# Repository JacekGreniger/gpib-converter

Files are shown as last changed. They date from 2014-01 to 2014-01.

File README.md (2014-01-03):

gpib-converter
==============

GPIB to USB converter

Source code for the device published in Elektronika Praktyczna 2/2013

Short PB5 to GND during powering on to enter printer (dummy) mode. In this mode all data sent over GPIB
are transferred to PC (use your favourite terminal program to save data into file). Use this mode to get plots from your GPIB device (spectrum analyzer, oscilloscope).
Received plots can be rendered using KE5FX HP7470 emulator package. Printer mode can be also entered using
command "p".

ATmega32 is clocked using 12MHz clock taken from pin C0 of FT232RL USB to serial converter. Use programming
order as below:

1. Program FT232RL using proper utility (see hw/ft232_settings.jpg)
2. Program ATmega32 using ISP programmer (sw/gpib_conv_v4.hex)
3. Set proper fusebits (see hw/fusebits.jpg)

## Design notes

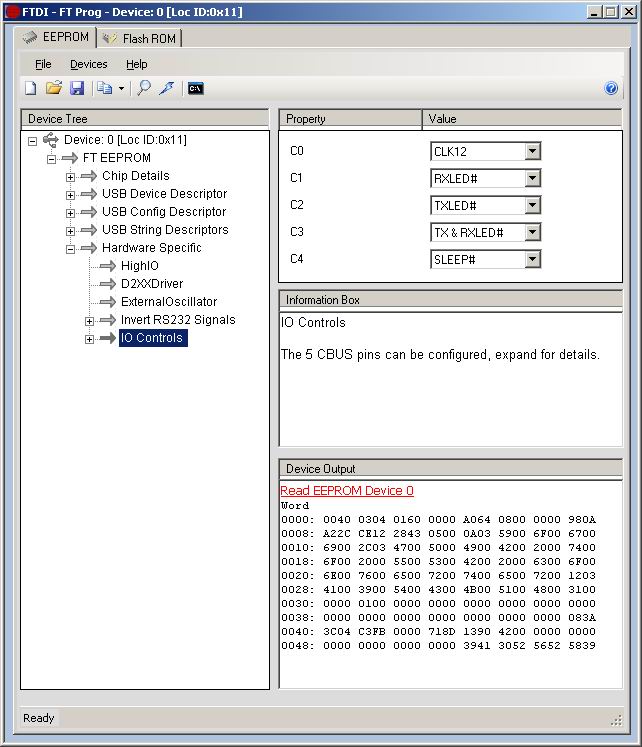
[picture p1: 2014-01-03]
hw/ft232_settings.jpg

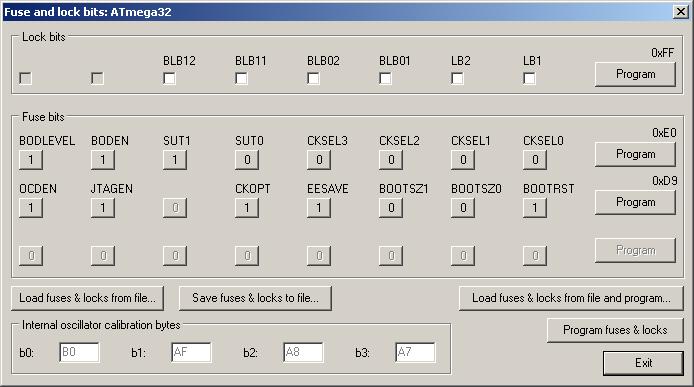
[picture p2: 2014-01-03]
hw/fusebits.jpg

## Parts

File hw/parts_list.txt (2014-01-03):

IC1 - ATmega32, TQFP44
IC2 - FT232RL
LED1 - LED 0805
R1 - 560ohm, 0805
C1 - 100nF, 0805
C2 - 4.7uF, 10V, B size
X1 - connector mini-usb (TME: ESB34101000Z, Farnell: 2112374)
Connector Wtyk 24pin Centronics (TME: CENTR-224, Farnell: 2112386)

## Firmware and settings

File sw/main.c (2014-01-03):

/* GPIB to USB converter
   ATMega32 + FT232RL
   clocked with external 12MHz taken from FT232RL (output 1)
   version 4, 20.08.2012
   
   Added feature:
    - possible to exit from printer mode
    - added help under command "?"
    - backspace support
    - commands scroll
    - printer mode, red led 
    - listen mode
    - M command for sending data without EOI
*/


#include <inttypes.h>
#include <stdio.h>
#include <stdlib.h>
#include <string.h>
#include <avr/io.h>
#include <stdbool.h>
#include <ctype.h>
#include "usart.h"
#include "avr/pgmspace.h"
#include <avr/interrupt.h>

#define F_CPU 12000000UL  
#include <util/delay.h>

#define DEFAULT_ADDRESS 21

/*
GPIB Connector pinout

Pin | Nazwa | Opis               | Source            | Atmega pin |	
----+-------+--------------------+-------------------+------------+--------
1   | DIO1  | Data bit 1 (LSB)   | Talker            | PA0	37    | X3-4
2   | DIO2  | Data bit 2         | Talker            | PA1	36    | X3-3
3   | DIO3  | Data bit 3         | Talker            | PA2	35    | X3-2
4   | DIO4  | Data bit 4         | Talker            | PA3	34    | X3-1
5   | EOI   | End Or Indentity   | Talker/Controller | PC7	26    | X4-1
6   | DAV   | Data Valid         | Controller        | PC6	25    | X4-2
7   | NRFD  | Not Ready For Data | Listener          | PC5	24    | X4-3
8   | NDAC  | No Data Accepted   | Listener          | PC4	23    | X4-4
9   | IFC   | Interface Clear    | Controller        | PC3	22    | X5-1
10  | SRQ   | Service Request    | Talker            | PC2	21    | X5-2
11  | ATN   | Attention          | Controller        | PC1	20    | X5-3
12  |       | Ekran              |                   |            |
13  | DIO5  | Data bit 5         | Talker            | PA4	33    | X2-4
14  | DIO6  | Data bit 6         | Talker            | PA5	32    | X2-3
15  | DIO7  | Data Bit 7         | Talker            | PA6	31    | X2-2
16  | DIO8  | Data bit 8 (MSB)   | Talker            | PA7	30    | X2-1
17  | REN   | Remote Enabled     | Controller        | PC0	19    | X5-4
18  |       | GND DAV            |                   |            |
19  |       | GND NRFD           |                   |            |
20  |       | GND NDAC           |                   |            |
21  |       | GND IFC	         |                   |            |
22  |       | GND SRQ	         |                   |            |
23  |       | GND ATN	         |                   |	          |
24  |       | GND data           |                   |	          | X3-5
*/

#define EOI (_BV(PC7))  //pin 26 ATmega, pin 5 GPIB
#define DAV (_BV(PC6))  //pin 25 ATmega, pin 6 GPIB
#define NRFD (_BV(PC5)) //pin 24 ATmega, pin 7 GPIB, output
#define NDAC (_BV(PC4)) //pin 23 ATmega, pin 8 GPIB, output
#define IFC (_BV(PC3))  //pin 22 ATmega, pin 9 GPIB
#define SRQ (_BV(PC2))  //pin 21 ATmega, pin 10 GPIB
#define ATN (_BV(PC1))  //pin 20 ATmega, pin 11 GPIB
#define REN (_BV(PC0))  //pin 19 ATmega, pin 17 GPIB

#define SetLed(x) ( PORTD = ((x==0)?(PORTD | _BV(PD2)) : (PORTD & ~_BV(PD2)) ))

#define SetEOI(x) ( PORTC = (x)? (PORTC | EOI) : (PORTC & ~EOI) )
#define SetDAV(x) ( PORTC = (x)? (PORTC | DAV) : (PORTC & ~DAV) )
#define SetNRFD(x) ( PORTC = (x)? (PORTC | NRFD) : (PORTC & ~NRFD) )
#define SetNDAC(x) ( PORTC = (x)? (PORTC | NDAC) : (PORTC & ~NDAC) )
#define SetIFC(x) ( PORTC = (x)? (PORTC | IFC) : (PORTC & ~IFC) )
#define SetSRQ(x) ( PORTC = (x)? (PORTC | SRQ) : (PORTC & ~SRQ) )
#define SetATN(x) ( PORTC = (x)? (PORTC | ATN) : (PORTC & ~ATN) )
#define SetREN(x) ( PORTC = (x)? (PORTC | REN) : (PORTC & ~REN) )

#define ESC_KEY_UP 0x41
#define ESC_KEY_DOWN 0x42
#define ESC_KEY_RIGHT 0x43
#define ESC_KEY_LEFT 0x44

#define MAX_COMMANDS 15
#define BUF_SIZE 64
#define GPIB_BUF_SIZE 128
#define GPIB_MAX_RECEIVE_TIMEOUT 50000
#define GPIB_MAX_TRANSMIT_TIMEOUT 50000
#define EMPTY_LINE 1

#define HELP_LINES 18
#define HELP_STRING_LEN 64
const char helpStrings[HELP_LINES][HELP_STRING_LEN] PROGMEM = {
  "GPIB to USB converter v4\r\n\r\n",
  "Transmit commands, OK/TIMEOUT/ERROR\r\n",
  "  <D> Data (ATN false), <M> Data without EOI\r\n",
  "  <C> Command (ATN true)\r\n",
  "  <T> Hex transmit (0C - command, 0D - data)\r\n",
  "Receive commands (receives until EOI,max 127 bytes)\r\n",
  "  <X> ASCII, <payload> or TIMEOUT\r\n",
  "  <Y> BINARY, <length><payload>\r\n",
  "  <Z> HEX, <length><payload>\r\n",
  "  <P> Continous read (plotter mode)\r\n",
  "General commands\r\n",
  "  <A> Set/get converter talk address\r\n",
  "  <S> Get REQ/SRQ/LISTEN state (1 if true)\r\n",
  "  <R> Set REMOTE mode (REN true)\r\n",
  "  <L> Set LOCAL mode (REN false)\r\n",
  "  <I> Generate IFC pulse\r\n",
  "  <E> Get/set echo on(E1)/off(E0)\r\n",
  "  <H> Commands history\r\n"
};


typedef enum {OFF = 0, SLOW, FAST} ledBlinking_t;
ledBlinking_t ledBlinking = OFF;
unsigned char listenAddress = DEFAULT_ADDRESS;
unsigned char msgEndSeq = 0;
unsigned char remoteState = 0;

/* ======================================================= */

void GPIO_init() {
  // DDR = 1 output
  // DDR = 0 input
  DDRD = 0x04; // PD2 output
  PORTD = 0x04; // leds off,

  DDRB = _BV(PB6); // PB6 output
  PORTB = _BV(PB5) | _BV(PB7); // PB5,PB7 pull-up
}


int uart_putchar(char ch, FILE* file)
{
  UART_transmit(ch);
  return ch;
}


void ReconfigureGPIO_GPIBReceiveMode()
{
  DDRA = 0x00; // PA0-PA7 inputs
  PORTA = 0xff; // pullup on
  
  DDRC = IFC | ATN | REN | NRFD | NDAC; // these lines are outputs, other as inputs
  PORTC = IFC | ATN | (remoteState?0:REN) | EOI | DAV | SRQ; // pullup on
}


void ReconfigureGPIO_GPIBNormalMode()
{
  DDRA = 0xff; // data lines are outputs
  PORTA = 0x00; // output level 0
  
  DDRC = IFC | ATN | REN | EOI | DAV; // these lines are outputs
  PORTC = IFC | ATN | (remoteState?0:REN) | EOI | DAV | SRQ | NRFD | NDAC; // pullup on
}


int GPIB_Receive(unsigned char * buf, unsigned char bufLength, unsigned char * receivedLength)
{
  unsigned char index = 0;
  unsigned char c;
  unsigned int timeout;

  do
  {
    SetNRFD(1); //ready for receiving data
    //-1 & 5
    
    timeout = 0;
    while (PINC & DAV) // waiting for falling edge
    {
      //_delay_ms(1);
      timeout++;
      if (timeout > GPIB_MAX_RECEIVE_TIMEOUT)
      {
        *receivedLength = index;
        SetNRFD(0);
        return 0;
      }
    }
    // 0
    
    SetNRFD(0); //not ready for receiving data
    // 1
    
    c = ~PINA; //read data

    buf[index++] = c;

    SetNDAC(1); //data accepted
    //2
    
    while (!(PINC & DAV)) // waiting for rising edge
    {
      //_delay_ms(1);
      timeout++;
      if (timeout > GPIB_MAX_RECEIVE_TIMEOUT)
      {
        *receivedLength = index;
        SetNDAC(0);
        return 0;
      }
    }
    //3
    
    SetNDAC(0);
    //4
  } while ((index < bufLength) /*&& (c != 13)*/);
  *receivedLength = index;
  return 255;
}


int GPIB_Receive_till_eoi(unsigned char * buf, unsigned char bufLength, unsigned char * receivedLength)
{
  unsigned char index = 0;
  unsigned char c;
  unsigned char eoi = 0;
  unsigned int timeout;

  do
  {
    SetNRFD(1); //ready for receiving data
    //-1 & 5
    
    timeout = 0;
    while (PINC & DAV) // waiting for falling edge
    {
      timeout++;
      if (timeout > GPIB_MAX_RECEIVE_TIMEOUT)
      {
        *receivedLength = index;
        SetNRFD(0);
        return 0;
      }
    }
    // 0
    
    if ((PINC & EOI) == 0)
      eoi = 1;
    
    SetNRFD(0); //not ready for receiving data
    // 1
    
    c = ~PINA; //read data

    buf[index++] = c;

    SetNDAC(1); //data accepted
    //2
    
    while (!(PINC & DAV)) // waiting for rising edge
    {
      timeout++;
      if (timeout > GPIB_MAX_RECEIVE_TIMEOUT)
      {
        *receivedLength = index;
        SetNDAC(0);
        return 0;
      }
    }
    //3
    
    SetNDAC(0);
    //4
  } while ((index < bufLength) && (eoi == 0));
  *receivedLength = index;
  return 255;
}


int GPIB_Receive_till_lf(unsigned char * buf, unsigned char bufLength, unsigned char * receivedLength)
{
  unsigned char index = 0;
  unsigned char c;
  unsigned int timeout;

  //SetNDAC(0);
  //SetNRFD(0);

  do
  {
    SetNRFD(1); //ready for receiving data
    //-1 & 5
    
    timeout = 0;
    while (PINC & DAV) // waiting for falling edge
    {
      timeout++;
      if (timeout > GPIB_MAX_RECEIVE_TIMEOUT)
      {
        *receivedLength = index;
        SetNRFD(0);
        return 0;
      }
    }
    // 0
       
    SetNRFD(0); //not ready for receiving data
    // 1
    
    c = ~PINA; //read data

    buf[index++] = c;

    SetNDAC(1); //data accepted
    //2
    
    while (!(PINC & DAV)) // waiting for rising edge
    {
      timeout++;
      if (timeout > GPIB_MAX_RECEIVE_TIMEOUT)
      {
        *receivedLength = index;
        SetNDAC(0);
        return 0;
      }
    }
    //3
    
    SetNDAC(0);
    //4
  } while ((index < bufLength) && (c != 10));
  *receivedLength = index;
  return 255;
}


int GPIB_Transmit(unsigned char * buf, unsigned char bufLength, unsigned char eoi)
{
  unsigned char index = 0;
  unsigned int timeout;
  
  if ((0 == bufLength) || ((PINC & NRFD) && (PINC & NDAC)))
    return 0;
  
  do
  {
    if ((index+1 == bufLength) && eoi)
      SetEOI(0); // last byte
    
    //transmit debug    
    //printf("%02x ", buf[index]);
    
    PORTA = ~buf[index];
    index++;
    
    _delay_us(100);
     
    timeout = 0;
    while (!(PINC & NRFD)) // waiting for high on NRFD
    {
      timeout++;
      if (timeout > GPIB_MAX_TRANSMIT_TIMEOUT)
      {
        SetEOI(1);
        return 0;
      }
    }
    
    SetDAV(0);
    _delay_us(100);
   
    while (!(PINC & NDAC)) // waiting for high on NDAC
    {
      timeout++;
      if (timeout > GPIB_MAX_TRANSMIT_TIMEOUT)
      {
        SetEOI(1);
        SetDAV(1);
        return 0;
      }
    }
    
    SetEOI(1);
    SetDAV(1);
    //4
  } while ((index < bufLength));

  //printf("\r\n");
  return 255;
}


void ShowHelp()
{
  char buf[64];
  unsigned char i;

  for (i=0; i<HELP_LINES; i++)
  {
    memcpy_P(buf, helpStrings[i], HELP_STRING_LEN);
    printf("%s", buf);
  }
}


char UART_RcvEscapeSeq()
{
  while (!UARTDataAvailable());
  if (UART_receive() != 0x5B)
    return 0;
  while (!UARTDataAvailable());
  return UART_receive();
}

#define T0_INIT 128 //177 = 255-78  daje 10ms dla 8MHz, 79=255-156 dla 16MHz

SIGNAL (SIG_OVERFLOW0) {
  static unsigned char timCnt = 0;
  static unsigned char led = 0;
  TCNT0 = T0_INIT; 
  if (OFF == ledBlinking)
    return;
	
  timCnt++;
  if (timCnt >= ((ledBlinking==SLOW)?25:5))
  {
    timCnt = 0;
    led = !led;
    SetLed(led);
  }
}


#define ishexdigit(x) \
       (((x >= '0') && (x <= '9')) ||   \
        ((x >= 'A') && (x <= 'F')))


unsigned char hex2dec(unsigned char x)
{
  if ((x >= '0') && (x <= '9'))
    return (x-'0');
  else
    return (10+x-'A');
}


unsigned char CheckHexMsg(unsigned char * buf, unsigned char len, unsigned char *outputMsg, unsigned char *outputLen, unsigned char *eoi)
{
  unsigned char i; 
  *eoi = 1; //default

  if (('D'==toupper(buf[1])) && (';'==buf[len-1]))
  {
    --len;
    *eoi = 0;
  }

  if ((len & 0x01) || (len < 4))
    return 0; //msg length is not even
    
  if (('0'!=buf[0]) || (('C'!=toupper(buf[1])) && ('D'!=toupper(buf[1]))))
    return 0;
    
  for (i=2; i<len; i++)
  {
    if (!ishexdigit(toupper(buf[i])))
      return 0;
  }

  *outputLen = 0;
  
  for (i=2; i<len; i=i+2)
  {
    *outputMsg = hex2dec(toupper(buf[i])) << 4;
    *outputMsg += hex2dec(toupper(buf[i+1]));
    //printf("%d ", *outputMsg);
    outputMsg++;
    *outputLen += 1;
  }
  //printf("\r\n");
  return 1;
}

char commandsHistory[BUF_SIZE*MAX_COMMANDS];
char savedCommands = 0;
char selectedCommand = 0;

unsigned char listenMode = 0;
unsigned char listenMode_prev = 0;

unsigned char buf[BUF_SIZE+4];
unsigned char msgBuf[BUF_SIZE+4];
unsigned char gpibBuf[GPIB_BUF_SIZE];

void main(void) 
{
  unsigned char bufPos = 0;
  unsigned char cursorPos = 0;
  unsigned char localEcho = 1;
  unsigned char c;
  int i;
  unsigned char gpibIndex = 0;
  unsigned char command = 0;
  int result = 0;
  unsigned char msgLen = 0;
  unsigned char msgEOI = 1;

  GPIO_init();
  
/* timer & interrupt initialize */
  TIMSK = _BV(TOIE0);        // wlacz obsluge przerwan T/C0
  TCNT0 = T0_INIT;         // wartosc poczatkowa T/C0
  TCCR0 = _BV(CS00)|_BV(CS02); // preskaler 1024
  sei();
  
  ReconfigureGPIO_GPIBNormalMode();
  UART_init();
  fdevopen(uart_putchar, NULL);
  
#if 1 
  if (0 == (PINB & _BV(PB5))) // printer mode
  {
    ledBlinking = SLOW;
    ReconfigureGPIO_GPIBReceiveMode();
    _delay_ms(1);

    while (1)
    {
      result = GPIB_Receive(gpibBuf, GPIB_BUF_SIZE-2, &gpibIndex);
      if (gpibIndex != 0)
      {
        for (i=0; i<gpibIndex; i++)
          UART_transmit(gpibBuf[i]);
      }
      else
      {
        _delay_ms(10);
      }
    }
  }

  localEcho = (PINB & _BV(PB7))?1:0;
#endif

  SetLed(1);
  
  while (1) //main loop
  {
    selectedCommand = savedCommands;
    
    if (localEcho && !bufPos)
      printf("<GPIB> ");
      
    do
    {
      while (!UARTDataAvailable());
      c = UART_receive();

      if (0x08 == c) //backspace
      {
        if ((bufPos > 0) && (cursorPos == bufPos))
        {
          --bufPos;
          --cursorPos;
          if (localEcho)
          {
            UART_transmit(0x08);
            UART_transmit(' ');
            UART_transmit(0x08);
          }
        }
        else if ((bufPos > 0) && (cursorPos > 0))
        {
          --bufPos;
          --cursorPos;
          memmove(&buf[cursorPos], &buf[cursorPos+1], bufPos-cursorPos);
          if (localEcho)
          {
            UART_transmit(0x08);
            buf[bufPos] = 0;
            printf("%s ", &buf[cursorPos]);
            for (i=cursorPos; i<(bufPos+1); i++)
              UART_transmit(0x08);
          }
        }
      }
      else if (10 == c) //ignore LF
      {
      }
/*      else if (9 == c) //tab key
      {
        printf("<bufPos=%d cursorPos=%d>", bufPos, cursorPos);
      }
*/      else if (0x1b == c) //escape character
      {
        switch (UART_RcvEscapeSeq())
        {
          case ESC_KEY_UP:
            selectedCommand = selectedCommand?selectedCommand-1:0;
            memmove(&buf[0], &commandsHistory[selectedCommand*BUF_SIZE], BUF_SIZE);
            if (localEcho)
            {
              while (cursorPos < bufPos)
              {
                UART_transmit(' ');
                cursorPos++;
              }
              while (bufPos--)
              {
                UART_transmit(0x08);
                UART_transmit(' ');
                UART_transmit(0x08);
              }
              printf("%s", &buf[0]);
            }
            bufPos = strlen((char*)&buf[0]);
            cursorPos = bufPos;
            break;
            
          case ESC_KEY_DOWN:
            if ((selectedCommand+1) == savedCommands) //current command is last command in buffer
            {
              selectedCommand = savedCommands;
              if (localEcho)
              {
                while (cursorPos < bufPos)
                {
                  UART_transmit(' ');
                  cursorPos++;
                }
                while (bufPos--)
                {
                  UART_transmit(0x08);
                  UART_transmit(' ');
                  UART_transmit(0x08);
                }
              }
              bufPos = 0;
              cursorPos = 0;
            }
            else if ((selectedCommand+1) < savedCommands) // <MAX_COMMANDS
            {
              selectedCommand++;
              memmove(&buf[0], &commandsHistory[selectedCommand*BUF_SIZE], BUF_SIZE);
              if (localEcho)
              {
                while (cursorPos < bufPos)
                {
                  UART_transmit(' ');
                  cursorPos++;
                }
                while (bufPos--)
                {
                  UART_transmit(0x08);
                  UART_transmit(' ');
                  UART_transmit(0x08);
                }
                printf("%s", &buf[0]);
              }
              bufPos = strlen((char*)&buf[0]);
              cursorPos = bufPos;
            }
            break;
            
          case ESC_KEY_LEFT:
            if (cursorPos)
            {
              --cursorPos;
              if (localEcho)
              {
                UART_transmit(0x1B);
                UART_transmit(0x5B);
                UART_transmit('D');
              }
            }
            break;
            
          case ESC_KEY_RIGHT:
            if (cursorPos < bufPos)
            {
              cursorPos++;
              if (localEcho)
              {
                UART_transmit(0x1B);
                UART_transmit(0x5B);
                UART_transmit('C');
              }
            }
            break;
            
          default:
            break;
        }
      }
      else if (13 == c)
      {
        if (localEcho)
        {
          UART_transmit(13); //CR
          UART_transmit(10); //LF
        }
		
        if (bufPos)
          command = toupper(buf[0]);
        else
          command = EMPTY_LINE;
      }
      else
      {
        if (bufPos < BUF_SIZE-1)
        {
          if (cursorPos == bufPos)
          {
            buf[bufPos++] = c;
            cursorPos++;
            if (localEcho)
              UART_transmit(c); //local echo
          }
          else
          {
            memmove(&buf[cursorPos+1], &buf[cursorPos], bufPos-cursorPos);
            buf[cursorPos++] = c;
            bufPos++;
            buf[bufPos] = 0;
            if (localEcho)
            {
              UART_transmit(c); //local echo
              printf("%s", &buf[cursorPos]);
              for (i=cursorPos; i<bufPos; i++)
                UART_transmit(0x08);
            }
          }
        }
      }
    } while (!command);
    

    if ('D' == command) //send data
    {
      if (!listenMode)
      {
        if (1 == msgEndSeq)
          buf[bufPos++] = 13; //CR
        else if (2==msgEndSeq)
          buf[bufPos++] = 10; //LF
        else if (3==msgEndSeq)
        {
          buf[bufPos++] = 13; //CR
          buf[bufPos++] = 10; //LF
        }
		
        result = GPIB_Transmit(buf+1, bufPos-1, 1); 
        if (result == 255) // transmit ok
          printf("OK\r\n");
        else //timeout
          printf("TIMEOUT\r\n");

        if ((1==msgEndSeq) || (2==msgEndSeq))
          --bufPos;
        else if (3==msgEndSeq)
          bufPos -= 2;
      }
      else
        printf("ERROR\r\n");	  
    }
    else if ('M' == command) //send data without EOI
    {
      if (!listenMode)
      {
        if (1 == msgEndSeq)
          buf[bufPos++] = 13; //CR
        else if (2==msgEndSeq)
          buf[bufPos++] = 10; //LF
        else if (3==msgEndSeq)
        {
          buf[bufPos++] = 13; //CR
          buf[bufPos++] = 10; //LF
        }
		
        result = GPIB_Transmit(buf+1, bufPos-1, 0); 
        if (result == 255) // transmit ok
          printf("OK\r\n");
        else //timeout
          printf("TIMEOUT\r\n");

        if ((1==msgEndSeq) || (2==msgEndSeq))
          --bufPos;
        else if (3==msgEndSeq)
          bufPos -= 2;
      }
      else
        printf("ERROR\r\n");	  
    }
    else if ('C' == command) //send command
    {
      for (i=1; i<bufPos; i++)
      {
        if ((buf[i] == '?') || (buf[i] == (64+listenAddress)))//unlisten
        {
          listenMode = 0;
          ledBlinking = OFF;
          SetLed(1);
        }
        else if (buf[i] == (32+listenAddress))
        {
          listenMode = 1;
          ledBlinking = FAST;
        }
      }

      if (1 == msgEndSeq)
        buf[bufPos++] = 13; //CR
      else if (2==msgEndSeq)
        buf[bufPos++] = 10; //LF
      else if (3==msgEndSeq)
      {
        buf[bufPos++] = 13; //CR
        buf[bufPos++] = 10; //LF
      }

      ReconfigureGPIO_GPIBNormalMode();

      SetATN(0);
      _delay_us(100);
      result = GPIB_Transmit(buf+1, bufPos-1, 1);
     
      if (result == 255) // transmit ok
        printf("OK\r\n");
      else //timeout
        printf("TIMEOUT\r\n");
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

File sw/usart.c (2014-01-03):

#include "usart.h"

#define FOSC 12000000UL // Clock Speed
#define BAUD 115200UL
#define MYUBRR FOSC/8/BAUD-1 //U2X set to 1

/* USART on */
void UART_init (void) {
  unsigned int ubrr = MYUBRR;
  UBRRH = (unsigned char)(ubrr>>8);
  UBRRL = (unsigned char)ubrr;
  UCSRA = (1<<U2X);
  /* Enable receiver and transmitter */
  UCSRB = (1<<RXEN) | (1<<TXEN);
  /* Set frame format: 8data, 1 stop bit, no parity */
  UCSRC = (1<<URSEL) | (3<<UCSZ0);
}

void UART_transmit( unsigned char data ) {
  /* Wait for empty transmit buffer */
  while ( !UARTTransmitBufferEmpty() );
  /* Put data into buffer, sends the data */
  UDR = data;
}

unsigned char UART_receive( void ) {
  /* Wait for data to be received */
  while ( !UARTDataAvailable() );
  /* Get and return received data from buffer */
  return UDR;
}
